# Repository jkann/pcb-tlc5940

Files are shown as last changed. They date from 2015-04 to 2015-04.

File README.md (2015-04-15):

# pcb-tlc5940
TLC5940-based multi-function board

Depending on the assembled components this can be one of the following:
(A) 16-channel servo control board
(B) 16-led bar display with idividual led dimming
(C) 5xRGB-led board, each with individial color

In each use case multiple board can be chained with regular 2.54mm jumpers (7x).
RGB-LEDS are spaced 10.0mm so that multiple 50mm x 50mm boards will extend the chain.

29-Apr-2015: Placed an order in iteadstudio.

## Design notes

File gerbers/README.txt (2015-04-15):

GENERAL:

- PCB thickness: 1.2 mm
- Surface finish: HASL
- Copper thickness: standard (1oz)
- Board size: 50mm x 50mm, rounded corners

PRODUCTION FILES:

- Top layer copper:         TLC5940Servo_F_Cu.gbr
- Bottom layer copper:      TLC5940Servo_B_Cu.gbr

- Top layer soldermask:     TLC5940Servo_F_Mask.gbr
- Bottom layer soldermask:  TLC5940Servo_B_Mask.gbr

- Top layer silkscreen:     TLC5940Servo_F_SilkS.gbr

- Board outline:            TLC5940Servo_Edge_Cuts.gbr

- Plated through holes:     TLC5940Servo.drl

- Non-plated through holes: TLC5940Servo_NPTH.drl

PROJECT DESCRIPTION:

TLC5940 based servo or LED control board.

SOURCES:
http://goo.gl/vWTvjd

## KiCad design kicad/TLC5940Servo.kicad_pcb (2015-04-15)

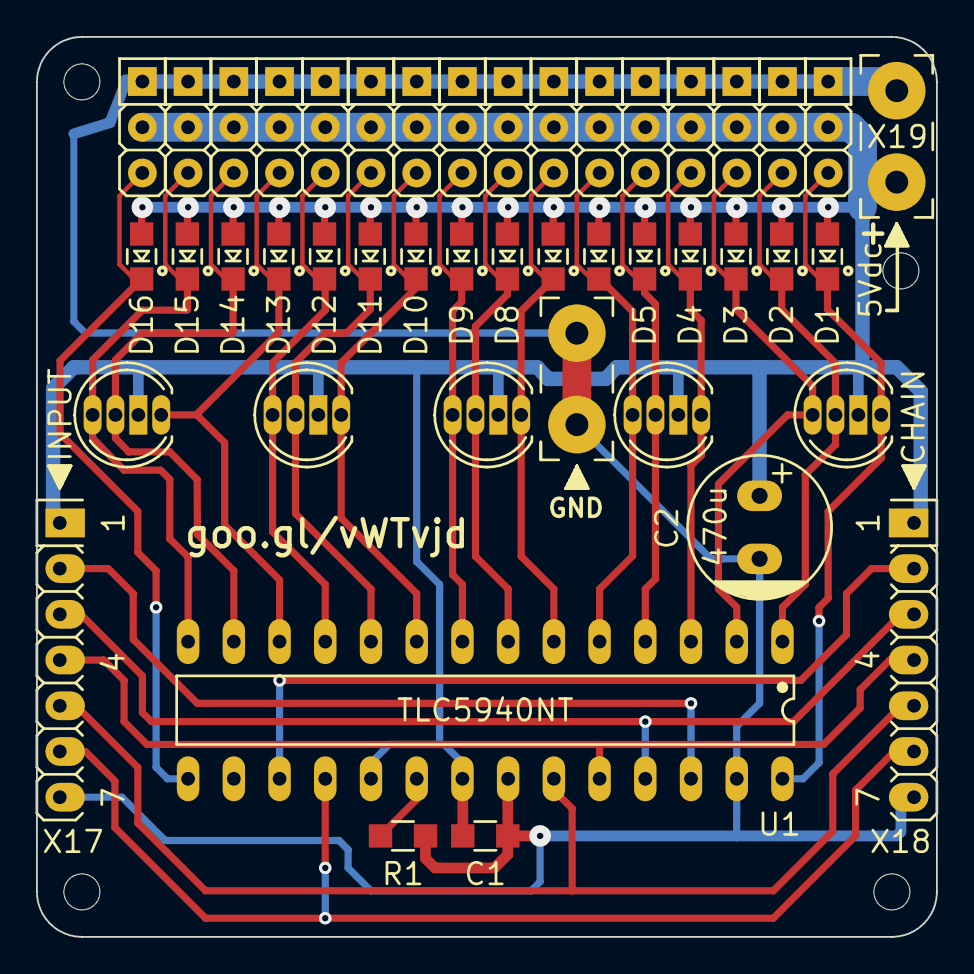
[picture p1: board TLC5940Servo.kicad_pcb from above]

Board: 2 copper layers, 50.0 x 50.0 mm, 49 parts (0 on the bottom side), 25 nets.

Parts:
2mm, 2mm#2, 2mm#3, 2mm#4: VAL**; JK_NPTH_2mm
C1: 100n; JK_0805_C
C2: 470u; JK_ELKO-d8-r3.5
D1, D2, D3, D4, D5, D6, D7, D8, D9, D10, D11, D12, D13, D14, D15, D16: JK_LED; JK_0805_LED
D17, D18, D19, D20, D21: JK_LED_RGB_CA; JK_LED_5MM_RGB
R1: 2k2; JK_0805_R
U1: TLC5940NT; JK_DIP-28N_N
X1, X2, X3, X4, X5, X6, X7, X8, X9, X10, X11, X12, X13, X14, X15, X16: JK_CONN_3; JK_PH-1x3_SSNM
X17: INPUT; JK_PH-1x7_SR
X18: CHAIN; JK_PH-1x7_SL
X19: 5Vdc; JK_WSP_2x0.75mm2_R
X20: TESTHOOK; JK_WSP_2x0.75mm2_R

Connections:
/BLANK: U1.23, X17.5, X18.5
/GSCLK: U1.18, X17.6, X18.6
/P00: D1.2, D17.1, U1.28, X1.3
/P01: D2.2, D17.3, U1.1, X2.3
/P02: D3.2, D17.4, U1.2, X3.3
/P03: D4.2, D18.1, U1.3, X4.3
/P04: D5.2, D18.3, U1.4, X5.3
/P05: D6.2, D18.4, U1.5, X6.3
/P06: D7.2, D19.1, U1.6, X7.3
/P07: D8.2, D19.3, U1.7, X8.3
/P08: D9.2, D19.4, U1.8, X9.3
/P09: D10.2, D20.1, U1.9, X10.3
/P10: D11.2, D20.3, U1.10, X11.3
/P11: D12.2, D20.4, U1.11, X12.3
/P12: D13.2, D21.1, U1.12, X13.3
/P13: D14.2, D21.3, U1.13, X14.3
/P14: D15.2, D21.4, U1.14, X15.3
/P15: D16.2, U1.15, X16.3
/SCLK: U1.25, X17.3, X18.3
/SIN: U1.26, X17.2
/SOUT: U1.17, X18.2
/XLAT: U1.24, X17.4, X18.4
GND: C1.2, C2.2, R1.1, U1.22, U1.27, X1.1, X2.1, X3.1, X4.1, X5.1, X6.1, X7.1, X8.1, X9.1, X10.1, X11.1, X12.1, X13.1, X14.1, X15.1, X16.1, X17.7, X18.7, X19.2, X20.1, X20.2
unnamed: R1.2, U1.20
VCC: C1.1, C2.1, D1.1, D2.1, D3.1, D4.1, D5.1, D6.1, D7.1, D8.1, D9.1, D10.1, D11.1, D12.1, D13.1, D14.1, D15.1, D16.1, D17.2, D18.2, D19.2, D20.2, D21.2, U1.19, U1.21, X1.2, X2.2, X3.2, X4.2, X5.2, X6.2, X7.2, X8.2, X9.2, X10.2, X11.2, X12.2, X13.2, X14.2, X15.2, X16.2, X17.1, X18.1, X19.1
